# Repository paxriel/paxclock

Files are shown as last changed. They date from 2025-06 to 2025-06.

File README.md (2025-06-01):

# Paxriel's Very Very Very Inefficient Clock

This is a 2x 4-digit 7-segment clock that is capable of the following features:

- Clock (Because its a clock)
- Stopwatch
- Timer
- Interval timer
- Brightness adjustment (Yes that's a feature now)

## Motivation

This was originally planned to be a retro-themed accessory for [LIFC 2025](https://www.littleislandfur.com/2025/) with a black and white theme to mimic the early digital radio clocks in the 80s. However, due to material limitations, this has converted into a early 2000s-ish transparent clock instead.

The main goal for the clock is to be:
- Stylish (Or as stylish as a retro clock can be)
- Portable (Either hung around the neck or on the wrist like a very ridiculously-sized watch)
- Useful even after the convention is over (i.e. convertible to desk clock)

## Software

This sketch requires the following in Arduino IDE to function properly:

### Board Manager

- ESP32 by Expressif

### Libraries

- ezButton by ArduinoGetStarted.com (v1.0.6)
- TonePitch by Rodrigo Dornelles (v1.0.3, actually this is originall planned cos I wanted a 2-buzzer setup but afterwards I found out that its a lot more complicated so out of the window it goes)
- Rtc by Makuna by Michael C. Miller (v2.5.0)
- TM1637 by Avishay Orpaz (v1.2.0)

## Electronics

This sketch runs on a ESP32 C3 Supermini as its base with the following components:
- DS3231 Module ([AliExpress](https://www.aliexpress.com/item/1005008494490890.html), the header pins, charging resistor and LED resistor are desoldered to allow it to work with a CR2032 battery)
- 2x 4-digit TM1637 7-segment display (1 red (5643BS-1), 1 green (5643BG)) ([AliExpress](https://www.aliexpress.com/item/1005001582129952.html))
- 3x Push-buttons ([AliExpress](https://www.aliexpress.com/item/1005008340384363.html))
- 1x Buzzer ([AliExpress](https://www.aliexpress.com/item/1005008483688535.html))

After breadboarding, this is converted to a [PCB](./gerbers/) using KiCad and sent for printing at [JLCPCB](https://jlcpcb.com/).

This board can be powered either by plugging in the USB-C port in the ESP32 C3 Supermini using a computer or power bank, or it can be powered via a suitable 5V power supply by using the 5V and GND holes. The remaining pins which are not used also have holes on the PCB to allow the board to be reused in future projects.

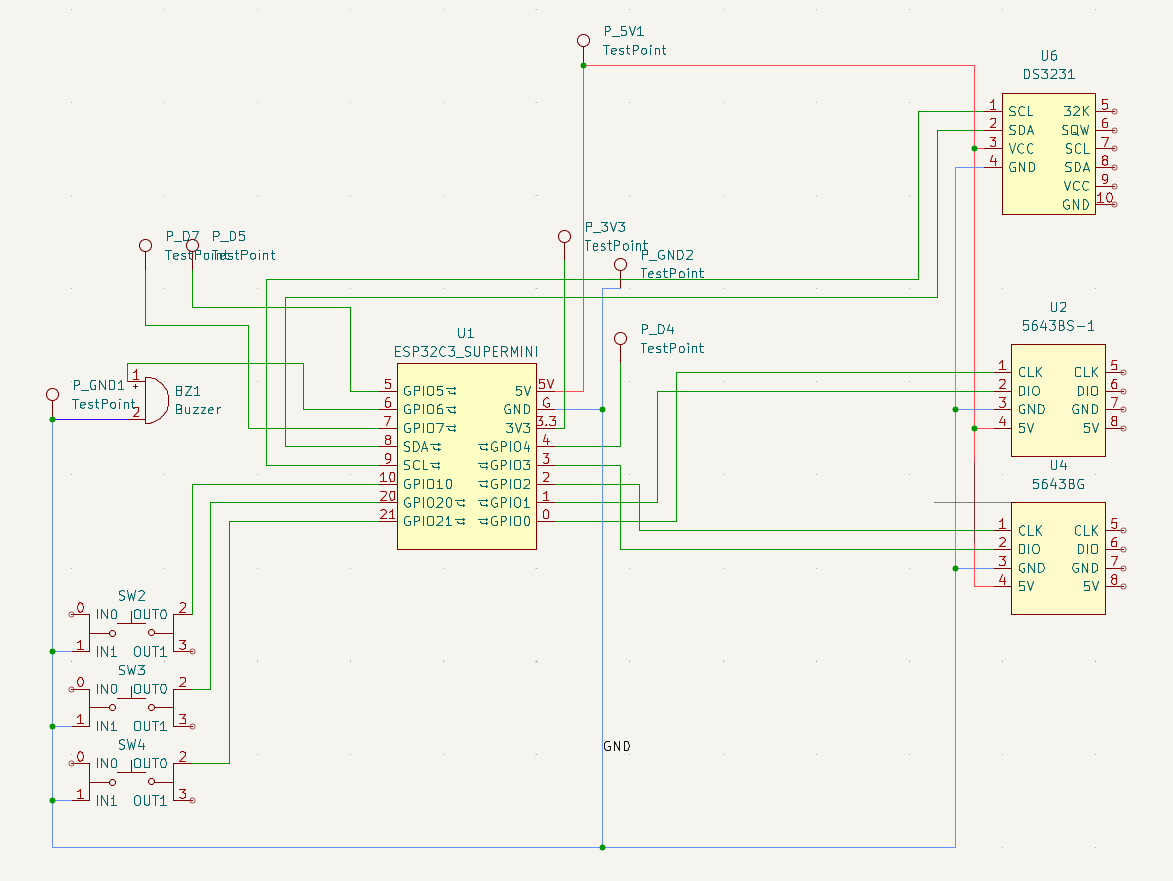
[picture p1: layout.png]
The pinout layout for this project.


With my available components, I was able to make 2 out of 5 fully assembled PCBs. Thus, I designated one to be powered by an external source and the other to be powered with 18650 batteries.

For the 18650-powered version, I also used the following components:
- 3x modular 21700 case ([AliExpress](https://www.aliexpress.com/item/1005007478530058.html), Becase 18650 cases are always too tight for some reason) - Do note that among the 9 cases that I ordered there are only 6 packs of screws for some reason, so I would recommend buying from an alternative vendor if possible
- 5V 3A buck converter ([AliExpress](https://www.aliexpress.com/item/1005005848104656.html), [AliExpress that I got it from](https://www.aliexpress.com/item/1005008257960729.html))
- 3-cell 18650 BMS board ([AliExpress](https://www.aliexpress.com/item/1005008762875220.html))
- 3-cell 18650 5V 2A charger board ([AliExpress](https://www.aliexpress.com/item/1005006626174680.html), I didn't want to go with a PD charger in case it exceeds the batteries' charging current limit)
- Rocker switch ([AliExpress](https://www.aliexpress.com/item/1005007542513893.html))

The output of the 5V board is linked to the 5V and GND terminals on the main board using 14AWG wires.

## Hardware

The board that I designed had 8x M3 mounting holes which I mounted using nylon standoffs to the front of the case.

Initially, I attempted to make a [full 3D-printed case](./case/v1/) using FreeCAD and print via [JLC3DP](https://jlc3dp.com/). However, this was not practical as I found out that the case would take around 40 SGD to manufacture excluding shipping. Thus, I settled for 3D printing the [front covers](./case/v2/) and using acrylic sheets to form the rest of the case. The sheets are cut out and subsequently glued together.

For the back of the case, an additional acrylic panel with magnetic tape ([AliExpress](https://www.aliexpress.com/item/1005006757451588.html)) is glued to both the left and right sides of the panel. An additional layer of magnetic tape is also applied to the back of the case, allowing it to be attached and removed magnetically.

## Prototype issues

- The mounting holes for the DS3231 and RTC modules are misaligned, which while they are not used in this board may still pose an issue in future projects.
- My soldering iron came into contact with a few plastic parts during soldering, which causes them to be slightly melted but still usable.
- I did not account for the battery case mounting positions during the PCB design, which resulted in last-minute superglueing standoffs to the back of the battery case to attach it to the PCB board.

## Potential Improvements

- A hardware RC debounce can be added for the buttons, as even with software debouncing jitter can still occur if the same button is pressed too frequently.
- The TM1637 modules have a LED on their backs which I forgot to desolder, resulting in a green backlight on the final product.
- An additional center acrylic board could be installed to provide mounting points for the battery case.
- PCB design can be made more compact by moving the buzzer upwards to near the buttons, and the ESP32 C3 Supermini and RTC can be soldered to the back of the 7-segment displays instead of below it. This would've allowed it to fit within a conventional case instead of the 3D-printed case right now.
- Battery support could be built into the existing PCB instead of as separate boards, which would allow for an easier assembly process.

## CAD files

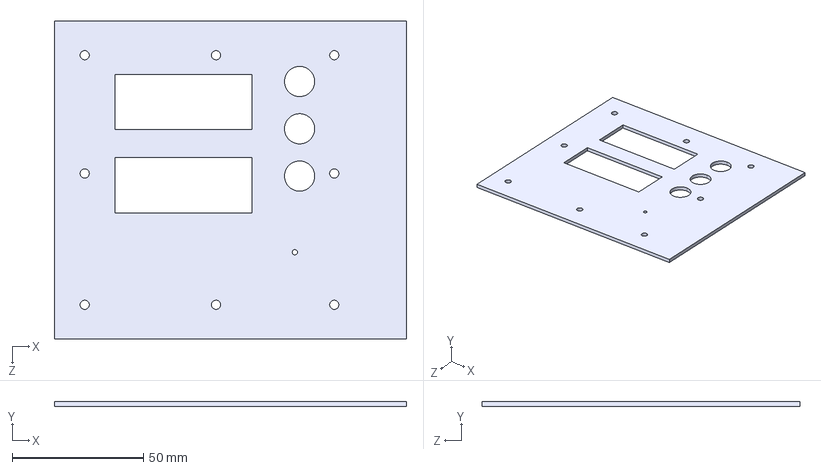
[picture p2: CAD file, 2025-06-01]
case/v2/Front Cover B.STEP
134.0 x 2.00 x 121.0 mm

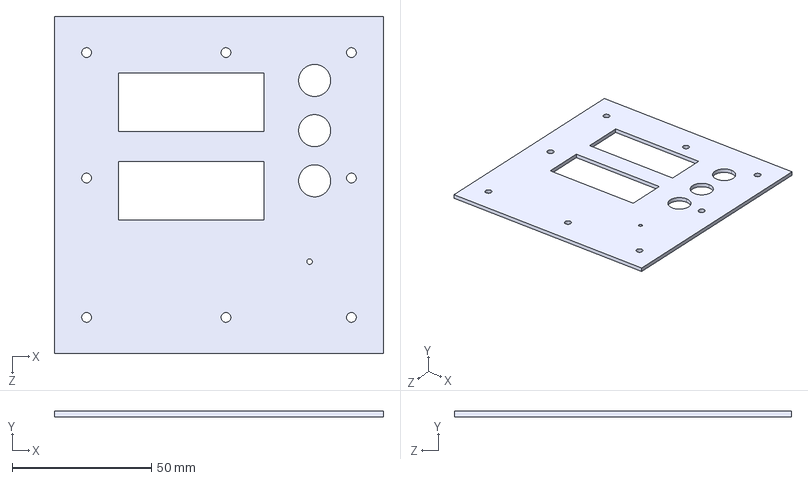
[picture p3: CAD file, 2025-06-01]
case/v2/Front Cover A.STEP
118.0 x 2.00 x 121.0 mm

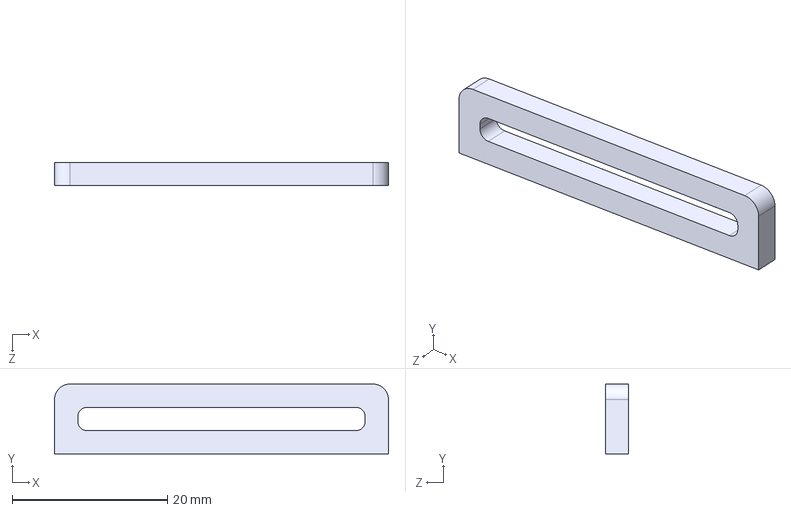
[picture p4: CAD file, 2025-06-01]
case/v2/20250515a Watch Strap Adapter Solo.STEP
43.0 x 9.00 x 3.00 mm

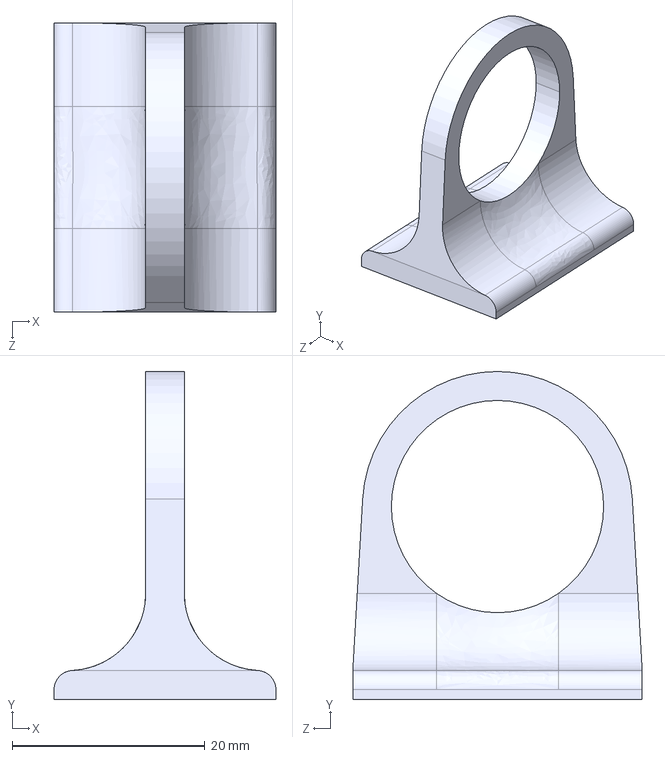
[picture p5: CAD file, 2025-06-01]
case/v2/20250515a Carabiner Adapter Solo.STEP
23.0 x 34.0 x 30.0 mm

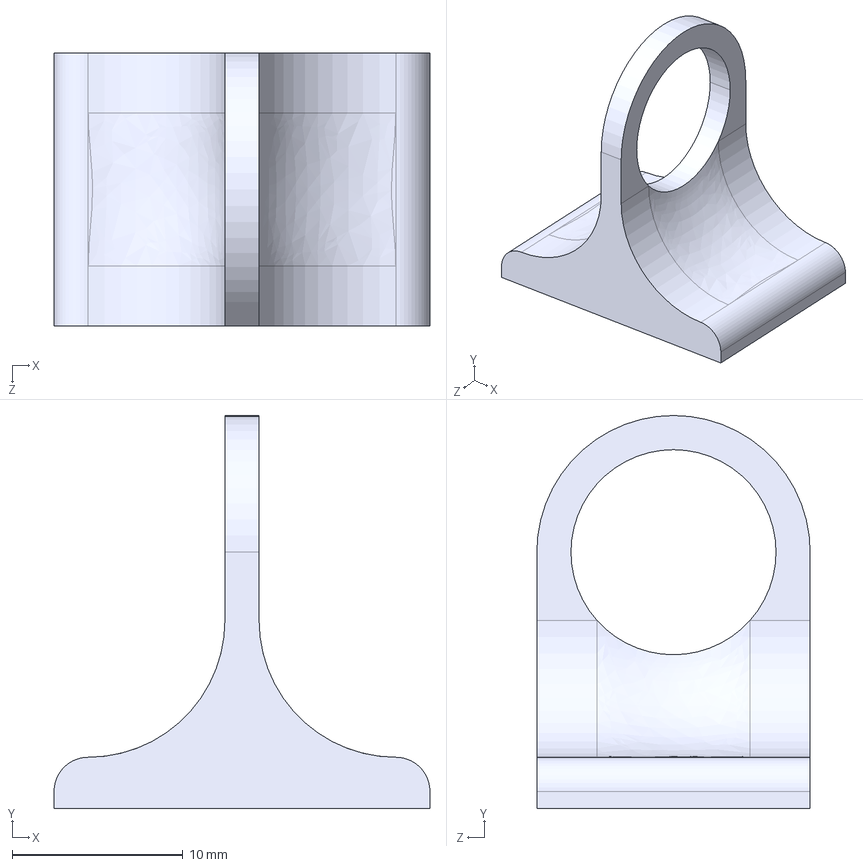
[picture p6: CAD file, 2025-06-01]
case/v2/20250515a Lanyard Adapter Solo.STEP
22.0 x 23.0 x 16.0 mm

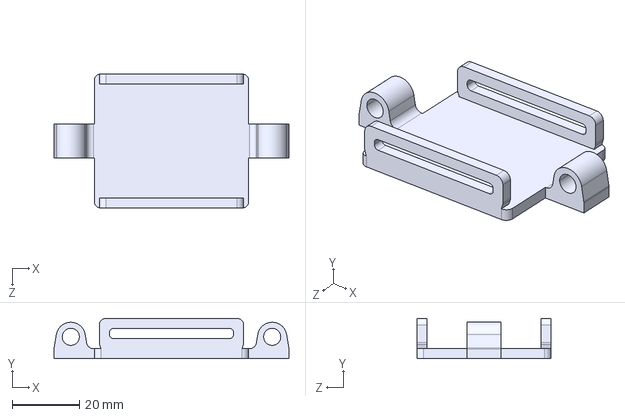
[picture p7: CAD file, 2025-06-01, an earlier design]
case/v1/20250515 Watch Strap Adapter.STEP
70.0 x 12.0 x 40.0 mm

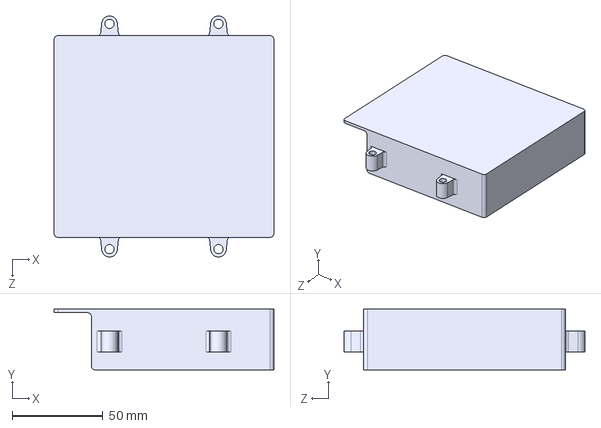
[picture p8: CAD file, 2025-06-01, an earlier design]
case/v1/20250515 Rear Case.STEP
121.0 x 33.5 x 132.7 mm

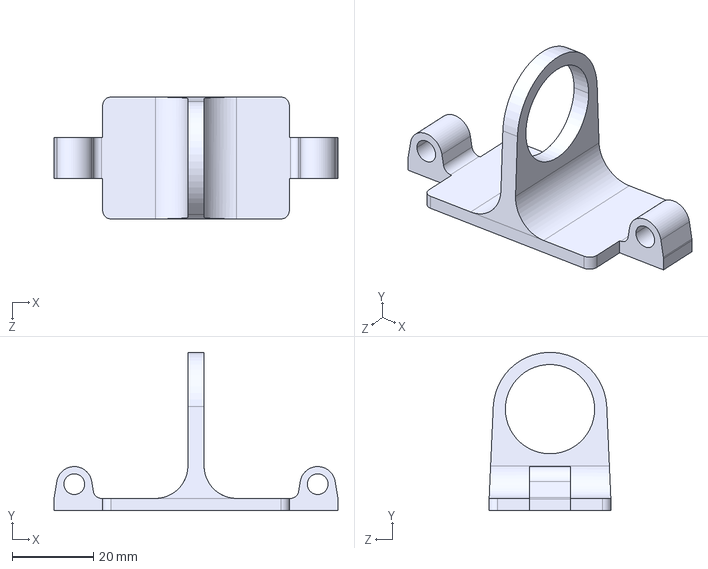
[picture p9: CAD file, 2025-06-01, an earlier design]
case/v1/20250515 Carabiner Adapter.STEP
70.0 x 39.0 x 30.0 mm

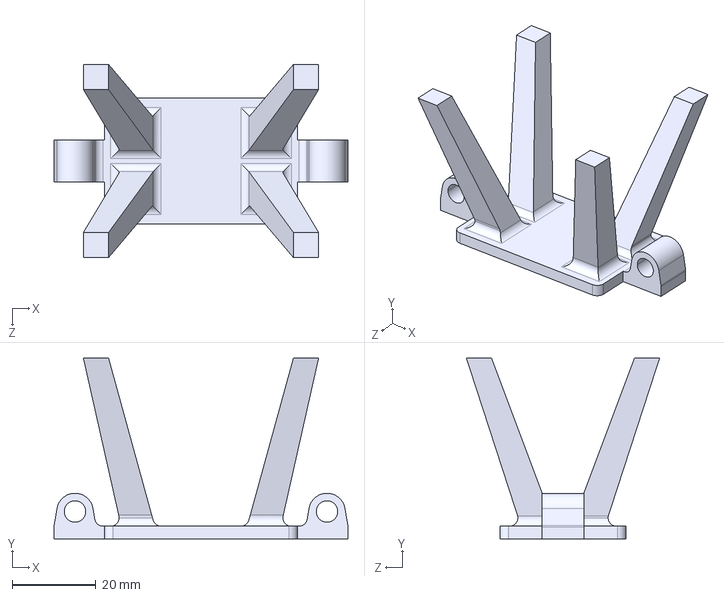
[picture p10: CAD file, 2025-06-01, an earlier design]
case/v1/20250515 Stand Adapter.STEP
70.0 x 43.0 x 46.0 mm

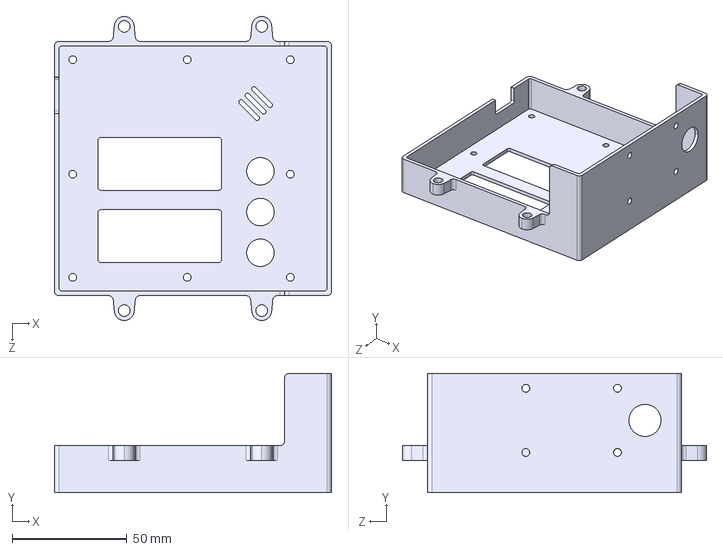
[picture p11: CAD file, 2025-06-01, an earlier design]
case/v1/20250515 Front Case v1.1.STEP
121.0 x 52.0 x 132.7 mm

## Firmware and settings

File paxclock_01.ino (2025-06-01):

#define TONE_USE_INT
#define TONE_PITCH 440

#include "esp_bt.h"
#include <ezButton.h>
#include <RtcDS3231.h>
#include <Wire.h> 
#include <Preferences.h>
#include <TM1637Display.h>
#include <TonePitch.h>
#include <WiFi.h>

#define I2C_SDA 8
#define I2C_SCL 9
#define RTC_SQW 5

#define R_CLK 2
#define R_DIO 3
#define G_CLK 0
#define G_DIO 1

#define BUTTON_NUM 3
#define BUTTON_PIN_MODE 10
#define BUTTON_PIN_INC 20
#define BUTTON_PIN_DEC 21
#define BUTTON_MODE 0
#define BUTTON_INC 1
#define BUTTON_DEC 2

#define MODE_COUNT 4
#define MODE_CLOCK 0
#define MODE_STOPWATCH 1
#define MODE_TIMER 2
#define MODE_INTERVAL_TIMER 3
#define MODE_ALARM_SET -2
#define MODE_SOUND_SET -1
#define MODE_BRIGHTNESS_SET 4

#define HOLD_PRE_INC 1
#define HOLD_PRE_DEC 2
#define HOLD_INC 3
#define HOLD_DEC 4

#define LONG_PRESS_DURATION 500
#define LONG_PRESS_INC_INTERVAL 200 // Increase target value by 1 every 200ms
#define INTERNAL_PRESCALER 80000 // Converts prescaler to 1 millis

#define BUZZER_0 6

#define countof(a) (sizeof(a) / sizeof(a[0]))

ezButton buttonArray[] = {
  ezButton(BUTTON_PIN_MODE),
  ezButton(BUTTON_PIN_INC),
  ezButton(BUTTON_PIN_DEC)
};

RtcDS3231<TwoWire> Rtc(Wire);
TM1637Display rd = TM1637Display(R_CLK, R_DIO);
TM1637Display gd = TM1637Display(G_CLK, G_DIO);
Preferences preferences;
bool pinChanged = false;
unsigned long debounceDelay = 50;

int modeState = 0; // 0 - Clock, 1 - Stopwatch, 2 - Timer, 3 - Interval timer, 4 - Alarm set, 5 - Sound Setting, 6 - Brightness Setting
bool modeChangeBlocked = false; // Used when adjusting things like timers, interval timers and alarms
unsigned long modePressedStart = 0;
unsigned long modePressedStop = 0;
unsigned long holdStart = 0;
int holdState = 0; // 0 - No hold, 1 - Pre-inc hold, 2 - Pre-dec hold, 3 - Inc hold, 4 - Dec hold

// Clock variables
int shownMth = 0;
int shownDay = 0;
int shownHr = 0;
int shownMin = 0;
RtcDateTime currentTime;
int clockState = 0; // 0 - Clock, 1 - Hours change, 2 - Minutes change, 3 - Month change, 4 - Day change, 5 - Year change, 6 - Alarm triggered

// Brightness variables (1-7)
int brightness = 1;
bool brightnessChanged = false;

// Stopwatch variables
RtcDateTime stStartRTC;
RtcDateTime stPausedRTC;
unsigned long stStartTime = 0; // Start time
unsigned long stPausedTime = 0; // Paused time
bool stPaused = true;

// Timer variables
unsigned long timerStartTime = 0; // Start time
unsigned long timerPausedTime = 0; // Paused time
unsigned long timerDuration = 1000*60*90; // Duration in millis
int timerState = 0; // 0 - Stopped, 1 - Running, 2 - Paused, 3 - Hrs set, 4 - Mins set, 5 - Triggered
bool timerDurationChanged = false;

// Interval timer variables
int activeSecs = 40;
int inactiveSecs = 20;
unsigned long intervalStartTime = 0;
unsigned long intervalPauseTime = 0;
int itState = 0; // 0 - Stopped, 1 - Running, 2 - Paused, 3 - Active set, 4 - Inactive set, 5 - Pre-start countdown
bool itDurationChanged = false;
bool itStateActive = false;

// Alarm variables
int alarmHr = 0;
int alarmMin = 0;
bool alarmEnabled = false;

void setup() {
  preferences.begin("paxclock", true);
  brightness = preferences.getInt("brightness", 2);
  activeSecs = preferences.getInt("activeSecs", 40);
  inactiveSecs = preferences.getInt("inactiveSecs", 20);
  timerDuration = preferences.getULong("timerDuration", 1000*60*90);
  alarmHr = preferences.getInt("alarmHr", 0);
  alarmMin = preferences.getInt("alarmMin", 0);
  alarmEnabled = preferences.getBool("alarmEnabled", false);
  preferences.end();

  init7Segment();
  //Serial.begin(115200);
  //while(!Serial); // Wait till serial initialized
  //Serial.println("Starting system...");
  Wire.begin(I2C_SDA, I2C_SCL);
  for (byte i = 0; i < BUTTON_NUM; i++) {
    buttonArray[i].setDebounceTime(100);
  }

  //lowerCPUFreq();
  offBtWifi();
  initRTC();
  if (buttonArray[1].getStateRaw() == 0 && buttonArray[2].getStateRaw() == 0) showTimeReset();
  else tone(BUZZER_0, NOTE_A4, 200);
  // else showCpuFreq();
  setMode();
}

void setMode() {
  checkStoredValueChange();
  rd.clear();
  rd.setBrightness(brightness);
  gd.clear();
  gd.setBrightness(brightness);
  switch (modeState) {
    case MODE_CLOCK:
      if (clockState == 6) showAlarm();
      else showCurrentTime(Rtc.GetDateTime());
      break;
    case MODE_STOPWATCH:
      showStopwatch();
      break;
    case MODE_TIMER:
      showTimer();
      break;
    case MODE_INTERVAL_TIMER:
      showIntervalTimer();
      break;
    case MODE_ALARM_SET:
      break;
    case MODE_SOUND_SET:
      break;
    case MODE_BRIGHTNESS_SET:
      showBrightnessSetting();
      break;
    default:
      break;
  }
}

// Check if any changes need to be stored to the permanent flash
void checkStoredValueChange() {
  if (brightnessChanged) {
    preferences.begin("paxclock", false);
    preferences.putInt("brightness", brightness);
    preferences.end();
  }
}

void checkAlarm() {
  if (!alarmEnabled) return;
  RtcDateTime now = Rtc.GetDateTime();
  if (now.Minute() == alarmMin && now.Hour() == alarmHr) clockState = 6;
  if (modeState != MODE_CLOCK && clockState == 6 && !modeChangeBlocked) {
    modeState = MODE_CLOCK;
    setMode();
  }
}

// Disable BT and Wifi
void offBtWifi() {
  esp_bt_controller_disable();
  esp_bt_controller_deinit();
  esp_bt_mem_release(ESP_BT_MODE_BTDM);
  WiFi.disconnect(true);
  WiFi.mode(WIFI_OFF);
}

/*
// Monitors frequency used by CPU; Frequency is set under 'Tools' in IDE (Current: 40 MHz)
void lowerCPUFreq() {
  // Print the XTAL crystal frequency
  Serial.print("XTAL Crystal Frequency: ");
  Serial.print(getXtalFrequencyMhz());
  Serial.println(" MHz");

  // Print the CPU frequency
  Serial.print("CPU Frequency: ");
  Serial.print(getCpuFrequencyMhz());
  Serial.println(" MHz");

  // Print the APB bus frequency
  Serial.print("APB Bus Frequency: ");
  Serial.print(getApbFrequency());
  Serial.println(" Hz");
}
*/

void loop() {
  unsigned long cMillis = millis();
  pinChanged = false;
  for (byte i = 0; i < BUTTON_NUM; i++) buttonArray[i].loop();

  for (byte i = 0; i < BUTTON_NUM; i++) {
    if (buttonArray[i].isPressed()) {
      // Rising edge triggers
      triggerRisingEdge(i, cMillis);
      pinChanged = true;
    }

    if (buttonArray[i].isReleased()) {
      triggerFallingEdge(i);
      pinChanged = true;
    }
  }

  /*
  if (pinChanged) {
    Serial.print("Buttons - Mode: " + String(buttonArray[0].getState()) + " Inc: " + String(buttonArray[1].getState()) + " Dec: " + String(buttonArray[2].getState()) + "\n");
  } */

  unsigned long mCheck = cMillis % 1000;
  // Fires every cycle
  if (modeState == MODE_STOPWATCH && (!stPaused)) {
    showStopwatch();
  }
  if ((holdState == HOLD_PRE_INC || holdState == HOLD_PRE_DEC) && (cMillis - holdStart) > LONG_PRESS_DURATION) {
    holdStart = cMillis;
    if (holdState == HOLD_PRE_INC) holdState = HOLD_INC;
    else holdState = HOLD_DEC;
    tone(BUZZER_0, NOTE_E5, 200);
    onLongPressTrigger(holdState == HOLD_INC);
  } else if (holdState > 2 && (cMillis - holdStart) > LONG_PRESS_INC_INTERVAL) {
    holdStart = cMillis;
    onLongPressTrigger(holdState == HOLD_INC);
  }

  // Fires every 10ms per 500 ms
  if (mCheck < 11 || (mCheck >= 500 & mCheck < 510)) {
    showTimer(); // Checks if timer time has reached, will return if it is not timer currently

    if (modeState == MODE_CLOCK) {
      if (clockState == 6) showAlarm();
      else if (clockState > 0) showEditClock();
    }
    if (modeState == MODE_INTERVAL_TIMER && (itState == 3 || itState == 4)) {
      showEditIntervalTimer();
    }
  }

  // Clock change fires every 10ms per 1s
  if (mCheck < 11) {
    checkAlarm();

    if (modeState == MODE_CLOCK && clockState == 0) {
      RtcDateTime now = Rtc.GetDateTime();
      if (now.Minute() != shownMin) showCurrentTime(now);
    }
    if (modeState == MODE_INTERVAL_TIMER && (itState == 1 || itState == 5)) {
      showIntervalTimer();
    }
  }
}

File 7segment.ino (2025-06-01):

const uint8_t loadS[] = {
  SEG_D | SEG_E | SEG_F,                 // L
  SEG_A | SEG_B | SEG_C | SEG_D | SEG_E | SEG_F, // O
  SEG_A | SEG_B | SEG_C | SEG_E | SEG_F | SEG_G, // A
  SEG_B | SEG_C | SEG_D | SEG_E | SEG_G        // d
};
const uint8_t testS0[] = { 0xff, 0xff, 0xff, 0xff};
const uint8_t testS1[] = { SEG_A, SEG_B, SEG_C, SEG_D };
const uint8_t testS2[] = { SEG_E, SEG_F, SEG_G, 0xff };
const uint8_t s0S[] = {
  SEG_A | SEG_C | SEG_D | SEG_F | SEG_G, // S
  SEG_D | SEG_E | SEG_F | SEG_G, // t
  0x00, 0x00
};
const uint8_t itS[] = {
  SEG_E | SEG_F, // I
  SEG_D | SEG_E | SEG_F | SEG_G, // t
  0x00, 0x00
};
const uint8_t clchS[] = {
  SEG_A | SEG_D | SEG_E | SEG_F, // C
  SEG_D | SEG_E | SEG_F,         // L
  SEG_A | SEG_D | SEG_E | SEG_F, // C
  SEG_C | SEG_E | SEG_F | SEG_G // h
};
const uint8_t itchS[] = {
  SEG_E | SEG_F, // I
  SEG_D | SEG_E | SEG_F | SEG_G, // t
  SEG_A | SEG_D | SEG_E | SEG_F, // C
  SEG_C | SEG_E | SEG_F | SEG_G // h
};
const uint8_t songS[] = {
  SEG_A | SEG_C | SEG_D | SEG_F | SEG_G,  // S
  SEG_A | SEG_B | SEG_C | SEG_D | SEG_E | SEG_F, // O
  SEG_A | SEG_B | SEG_C | SEG_E | SEG_F, // N
  SEG_A | SEG_B | SEG_C | SEG_D | SEG_F | SEG_G // g
};
const uint8_t brS[] = {
  SEG_C | SEG_D | SEG_E | SEG_F | SEG_G, // b
  SEG_E | SEG_G, // r
  0x00, 0x00
};
const uint8_t numbersS[] = {
  SEG_A | SEG_B | SEG_C | SEG_D | SEG_E | SEG_F, // 0
  SEG_B | SEG_C, // 1
  SEG_A | SEG_B | SEG_D | SEG_E | SEG_G, // 2
  SEG_A | SEG_B | SEG_C | SEG_D | SEG_G, // 3
  SEG_B | SEG_C | SEG_F | SEG_G, // 4
  SEG_A | SEG_C | SEG_D | SEG_F | SEG_G,  // 5
  SEG_A | SEG_C | SEG_D | SEG_E | SEG_F | SEG_G, // 6
  SEG_A | SEG_B | SEG_C, // 7
  SEG_A | SEG_B | SEG_C | SEG_D | SEG_E | SEG_F | SEG_G, // 8
  SEG_A | SEG_B | SEG_C | SEG_D | SEG_F | SEG_G // 9
};
const uint8_t taS[] = {
  SEG_D | SEG_E | SEG_F | SEG_G, // t
  SEG_A | SEG_B | SEG_C | SEG_E | SEG_F | SEG_G, // A
  0x00, 0x00
};
const uint8_t tachS[] = {
  SEG_D | SEG_E | SEG_F | SEG_G, // t
  SEG_A | SEG_B | SEG_C | SEG_E | SEG_F | SEG_G, // A
  SEG_A | SEG_D | SEG_E | SEG_F, // C
  SEG_C | SEG_E | SEG_F | SEG_G // h
};
const uint8_t alyS[] {
  SEG_A | SEG_B | SEG_C | SEG_E | SEG_F | SEG_G, // A
  SEG_D | SEG_E | SEG_F,                 // L
  0x00, SEG_B | SEG_C | SEG_D | SEG_F | SEG_G // y
};
const uint8_t alnS[] {
  SEG_A | SEG_B | SEG_C | SEG_E | SEG_F | SEG_G, // A
  SEG_D | SEG_E | SEG_F,                 // L
  0x00, SEG_C | SEG_E | SEG_G // n
};
const uint8_t cpuS[] {
  SEG_A | SEG_D | SEG_E | SEG_F, // C
  SEG_A | SEG_B | SEG_E | SEG_F | SEG_G, // P
  SEG_B | SEG_C | SEG_D | SEG_E | SEG_F, // U
  0x00
};
const uint8_t battS[] {
  SEG_C | SEG_D | SEG_E | SEG_F | SEG_G, // b
  SEG_A | SEG_B | SEG_C | SEG_E | SEG_F | SEG_G, // A
  SEG_D | SEG_E | SEG_F | SEG_G, // t
  SEG_D | SEG_E | SEG_F | SEG_G // t
};
const uint8_t rtcS[] {
  SEG_E | SEG_G, // r
  SEG_D | SEG_E | SEG_F | SEG_G, // t
  SEG_A | SEG_D | SEG_E | SEG_F, // C
  0x00
};
const uint8_t holdS[] {
  SEG_C | SEG_E | SEG_F | SEG_G, // h
  SEG_A | SEG_B | SEG_C | SEG_D | SEG_E | SEG_F, // O
  SEG_D | SEG_E | SEG_F,                 // L
  SEG_B | SEG_C | SEG_D | SEG_E | SEG_G // d
};

// Modifies seq[] to contain the numbers
void overwriteWithNumbers(uint8_t* seq, int number, bool zeroRear = false, int leadingLimit = 3) {
  // RTL
  if (number == 0 && zeroRear) {
    seq[2] = numbersS[0];
    seq[3] = numbersS[0];
    return;
  }

  if (number > 10000) number %= 10000;
  int current = 3;
  while (number > 0) {
    int c = number % 10;
    number /= 10;
    seq[current] = numbersS[c];
    current -= 1;
  }
  while (current >= leadingLimit) {
    seq[current] = numbersS[0];
    current -= 1;
  }
}

// Modifies first 2 segments of seq[] to contain numbers
void overwriteFrontWithNumbers(uint8_t* seq, int number, bool showZero = false) {
  if (number == 0 && showZero) {
    seq[0] = numbersS[0];
    seq[1] = numbersS[0];
  }

  // Always show leading 0
  // RTL
  if (number > 100) number %= 100;
  seq[1] = numbersS[number % 10];
  seq[0] = numbersS[(number / 10) % 10];
}

void init7Segment() {
  rd.clear();
  rd.setBrightness(brightness);
  gd.clear();
  gd.setBrightness((brightness < 7) ? brightness + 1 : brightness);
  rd.setSegments(testS0);
  gd.setSegments(loadS);
}

void showTimeReset() {
  tone(BUZZER_0, NOTE_E5, 200);
  gd.clear();
  rd.clear();
  gd.setBrightness(brightness);
  rd.setBrightness(brightness);
  gd.setSegments(clchS);
  rd.setSegments(holdS);
  delay(2000);
  // Make sure that press is intentional and not cause of bounce
  if (buttonArray[1].getStateRaw() == 0 && buttonArray[2].getStateRaw() == 0) {
    Rtc.SetDateTime(RtcDateTime(__DATE__, __TIME__));
    tone(BUZZER_0, NOTE_A5, 200);
  } else {
    tone(BUZZER_0, NOTE_C5, 200);
  }
}

void showCurrentTime(RtcDateTime now) {
  shownMth = now.Month();
  shownDay = now.Day();
  shownHr = now.Hour();
  shownMin = now.Minute();
  currentTime = now;
  gd.showNumberDecEx(shownMth * 100 + shownDay, 0b00000000, true, 4, 0);
  rd.showNumberDecEx(shownHr * 100 + shownMin, 0b01000000, true, 4, 0);
}

void showAlarm() {
  
}

void showEditClock() {
  unsigned long cMillis = millis() % 1000;
  if (currentTime.Second() > 0) currentTime -= currentTime.Second();
  uint8_t gSegments[] = {0x00, 0x00, 0x00, 0x00};
  uint8_t rSegments[] = {0x00, 0x00, 0x00, 0x00};

  if (clockState != 1 || cMillis < 500 || holdState > 2) overwriteFrontWithNumbers(rSegments, currentTime.Hour(), true);
  if (clockState != 2 || cMillis < 500 || holdState > 2) overwriteWithNumbers(rSegments, currentTime.Minute(), true, 2);

  if (clockState < 5) {
    if (clockState != 3 || cMillis < 500 || holdState > 2) overwriteFrontWithNumbers(gSegments, currentTime.Month(), true);
    if (clockState != 4 || cMillis < 500 || holdState > 2) overwriteWithNumbers(gSegments, currentTime.Day(), true, 2);
    gd.setSegments(gSegments);
  } else if (cMillis < 500 || holdState > 2) {
    gd.showNumberDec(currentTime.Year(), true, 4, 0);
  } else {
    gd.clear();
  }
  rd.setSegments(rSegments);
}

void showLowBatt() {
  gd.clear();
  rd.clear();
  gd.setBrightness(brightness);
  rd.setBrightness(brightness);
  gd.setSegments(battS);
  rd.setSegments(rtcS);
  delay(5000);
}

void showCpuFreq() {
  gd.clear();
  rd.clear();
  gd.setBrightness(brightness);
  rd.setBrightness(brightness);
  gd.setSegments(cpuS);
  rd.showNumberDec(getCpuFrequencyMhz(), false, 4, 0);
  delay(1000);
}
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
